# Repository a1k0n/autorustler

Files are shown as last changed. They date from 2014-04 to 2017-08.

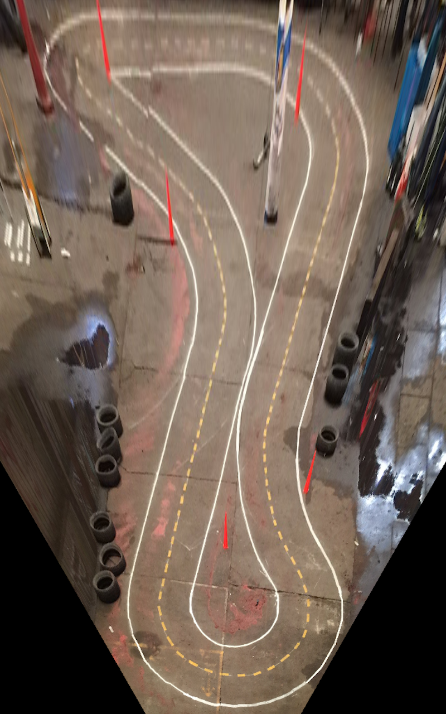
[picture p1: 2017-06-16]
diyrobocars/trackbirdseye.png

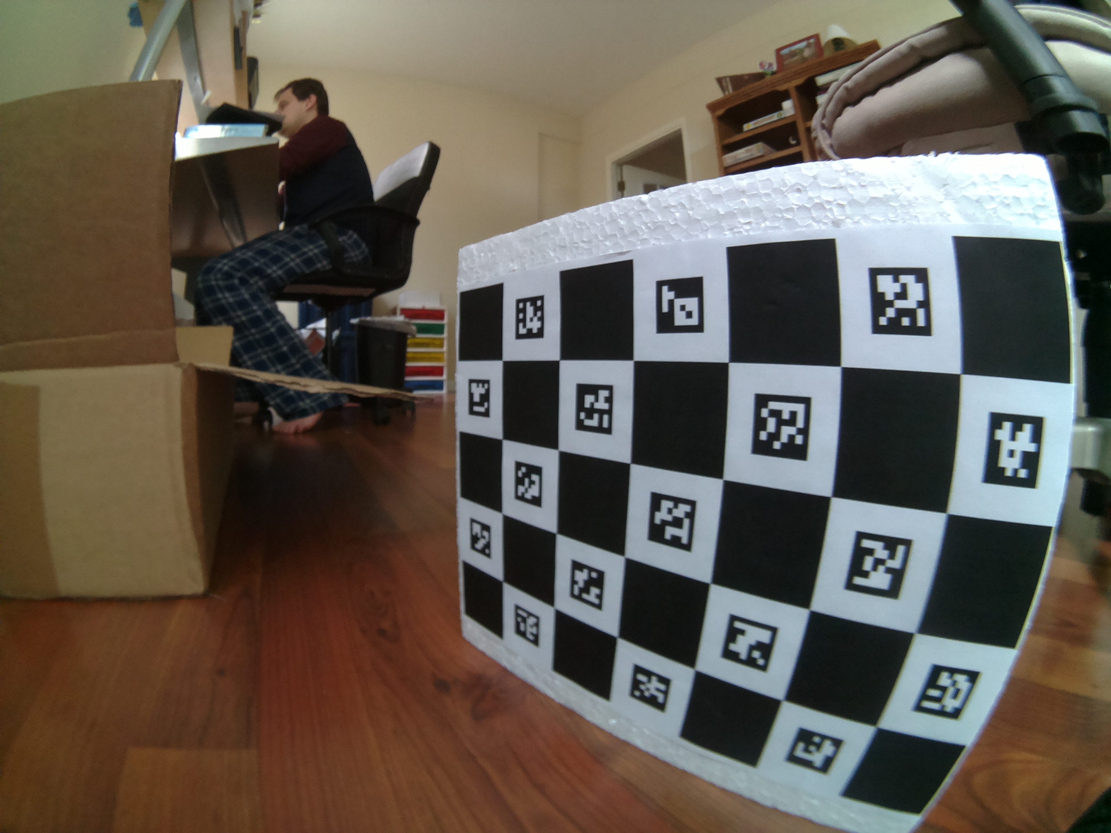
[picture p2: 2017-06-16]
camcal/cal2.jpg

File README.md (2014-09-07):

autorustler
===========

My work-in-progress self-driving RC car.

Most host code runs on a Raspberry Pi; some runs on an Atmel AVR connected to
it via SPI.

To build on a host with a raspberry pi cross-compiler (mine's called
arm-none-linux-gnueabi-gcc, you may need to edit crosscompile.cmake):

    mkdir build
    cd build
    cmake -DCMAKE_TOOLCHAIN_FILE=../crosscompile.cmake ..
    make -j4

Building on a raspberry pi is more straightforward but slow.

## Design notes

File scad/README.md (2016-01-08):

# OpenSCAD modelling for 3D-printed parts

The scad files reference some rather large .stl files (about 24MB total) for
lining up parts; type `make` to download them.

The Traxxas car model is from Claudio Caprarella:
https://grabcad.com/library/r-slash-c-car

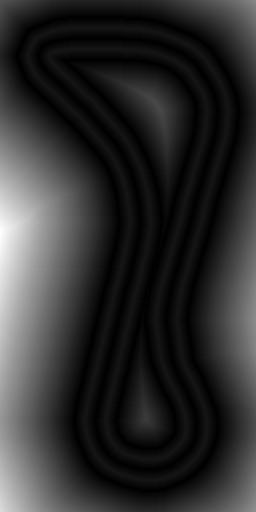
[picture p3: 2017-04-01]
diyrobocars/distmap.png

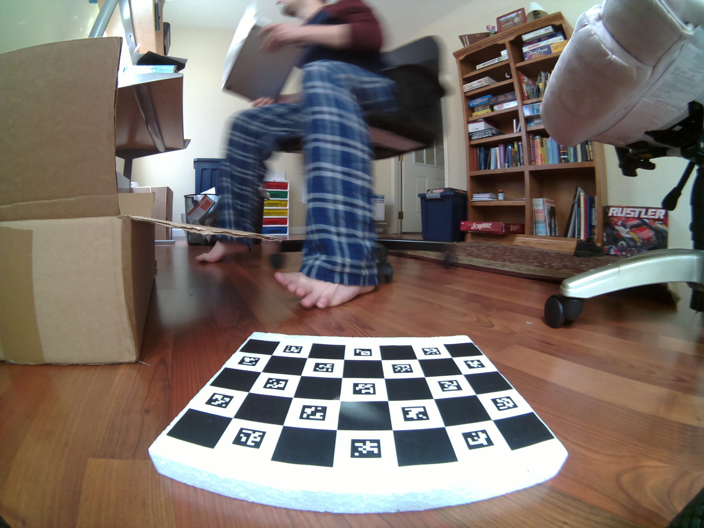
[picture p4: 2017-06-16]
camcal/cal4.jpg

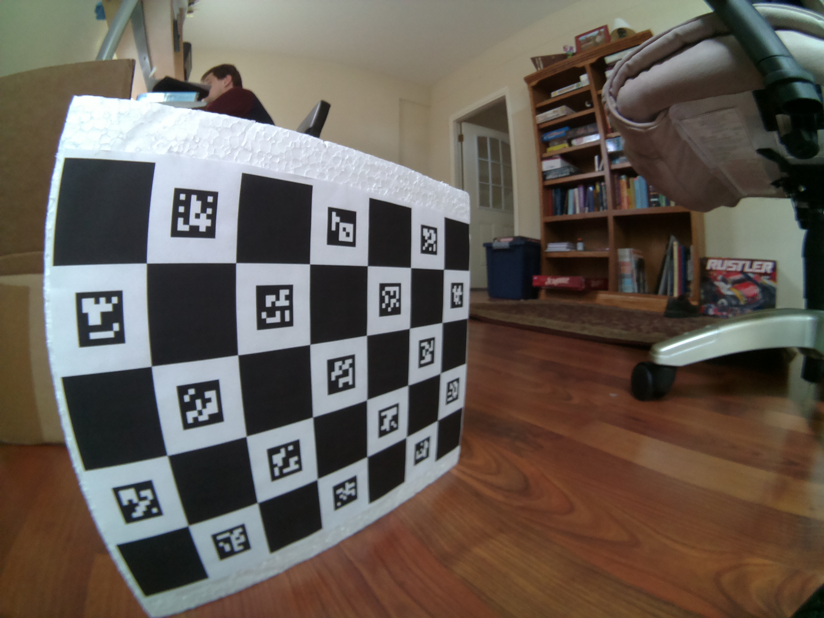
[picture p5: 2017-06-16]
camcal/cal3.jpg

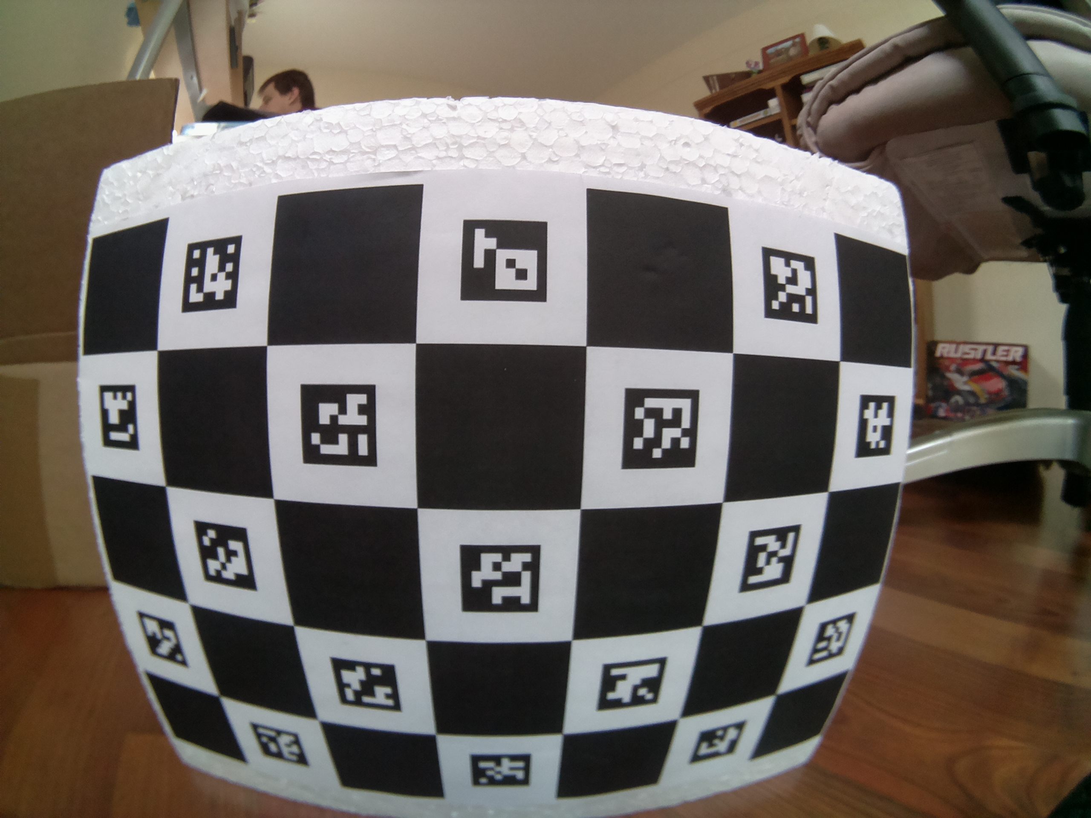
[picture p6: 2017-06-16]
camcal/cal1.jpg

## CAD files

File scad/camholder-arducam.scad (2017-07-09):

thickness = 7;
cam_border = 3;
arducam_width = 37;
arducam_height = 37;
arducam_mount = [
  [-28.5/2, 28.5/2],
  [-28.5/2, -28.5/2],
  [28.5/2, -28.5/2],
  [28.5/2, 28.5/2],
];
arducam_lens_diam = 18;
screw_diam = 2.26;  // #4-40
screw_wall_thickness = 1.2;  // must be a multiple of nozzle size 0.4
support_offset = 4;

module CameraMount() {
  difference() {
    union() {
      translate([-(cam_border + arducam_width)/2, -(cam_border + arducam_height)/2, 0])
        cube([cam_border + arducam_width, cam_border + arducam_height, thickness]);
      for (h = arducam_mount) {
        translate([h[0], h[1], thickness - 0.1]) {
          cylinder(d=screw_diam + 2*screw_wall_thickness, h=support_offset + 0.1, $fn=20);
        }
      }
    }
    for (h = arducam_mount) {
      translate([h[0], h[1], -0.1]) {
        cylinder(d=screw_diam, h=thickness + 10, $fn=10);
      }
    }
    // hole for lens
    translate([0, 0, -0.1])
      cylinder(d=arducam_lens_diam, h=thickness + 3);
  }
}

module BumperSpar(sparlen) {
  rotate([90, 0, 0]) rotate([0, 90, 0]) linear_extrude(height = 2)
    polygon(points=[
      [-1.72, 3.0],
      [sparlen, 3], [sparlen, -0.1], [0, -0.1], [-1.72, 3.0]]);
}

bb_len = 90;
module BumperBracket() {
  // 30.75 inner to inner
  // 3.5mm diameter holes (we will probably have to drill out)
  // 60 deg angle from vertical
  difference() {
    union() {
      rotate([-60, 0, 0]) {
        translate([-25, -20, 0])
          cube([50, 20, thickness]);
      }
      linear_extrude(height = thickness)
        polygon(points=[
            [-25, 0],
            [-(cam_border + arducam_width)/2, bb_len],
            [(cam_border + arducam_width)/2, bb_len],
            [25, 0], [-25, 0]]);
    }
    // translate([-12, 0, 1.0]) BumperSpar(bb_len - 5);
    // translate([10, 0, 1.0]) BumperSpar(bb_len - 5);
    rotate([-60, 0, 0]) {
      translate([-30.75/2 - 3.5/2, -6, -0.1])
        cylinder(d=4.5, h=thickness + 1, $fn=10);
      translate([-30.75/2 - 3.5/2, -6, thickness-0.1])
        cylinder(d=9, h=thickness + 1, $fn=20);
      translate([30.75/2 + 3.5/2, -6, -0.1])
        cylinder(d=4.5, h=thickness + 1, $fn=10);
      translate([30.75/2 + 3.5/2, -6, thickness-0.1])
        cylinder(d=9, h=thickness + 1, $fn=20);
    }
  }
}

BumperBracket();
translate([0, bb_len+arducam_height/2, 0]) CameraMount();

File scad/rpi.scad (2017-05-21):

// Raspberry Pi, in mm scale
// origin is centered at bottom of board
// most measurements are from my RPi own board with a dial calipers
// others from
// http://www.raspberrypi.org/raspberry-pi-rev2-template-with-mounting-holes/

RPi_length = 85;
RPi_width = 56;

RPi_mounting_holes = [
  [-RPi_length/2 + 5, -RPi_width/2 + 12.5],
  [RPi_length/2 - 25.5, RPi_width/2 - 18]
];

RPiCam_width = 25;
RPiCam_height = 24;
RPiCam_pcbdepth = 1;
RPiCam_mounting_holes = [
  [-RPiCam_width/2 + 2, RPiCam_height/2 - 2],
  [ RPiCam_width/2 - 2, RPiCam_height/2 - 2],
  [-RPiCam_width/2 + 2, -RPiCam_height/2 + 9.5],
  [ RPiCam_width/2 - 2, -RPiCam_height/2 + 9.5],
];

module HeaderPair() {
  color("black", alpha = 0.7)
    translate([0, 0, 2.5/2])
      cube([2.53, 5.08, 2.5], center=true);
  color("silver", alpha = 0.7) {
    translate([0, -1.27, 2.5])
      cube([0.6, 0.6, 11.5], center=true);
    translate([0, 1.27, 2.5])
      cube([0.6, 0.6, 11.5], center=true);
  }
}

module RPi() {
  // sd card protrusion
  sdcard_frombottom = 14;
  sdcard_width = 24;
  sdcard_bottom = RPi_width/2 - sdcard_frombottom;
  sdcard_center = sdcard_bottom - sdcard_width/2;

  pcb_h = 1.52;

  translate([0,0,pcb_h/2]) {
    // render sdcard first so it shows through the bottom
    translate([RPi_length/2 + 2, -sdcard_center, -.76-1.05])
      color([0, 0, 0, 0.5])
        cube([32, 24, 2.1], center = true);

    // circuit board itself, with mounting holes
    color([0, 0.4, 0, 0.5]) {
      difference() {
        cube([RPi_length, RPi_width, pcb_h], center = true);
        for (h = RPi_mounting_holes) {
          translate(h)
            cylinder(d = 2.9, h = 2, center = true, $fn = 20);
        }
      }
    }
  }

  // top & thru-hole components
  translate([0, 0, pcb_h - .01]) {
    // cpu & flat flex connectors
    color("black", alpha=0.7) {
      translate([-6 + 2.5, -6, 0]) cube([12, 12, 1.4]);
      translate([-RPi_length/2 + 25, RPi_width/2 - 22.5, 0]) cube([4, 22.5, 5.6]);
    }

    // P1 header is 1mm from the bottom-right
    for (i = [0 : 12]) {
      translate([RPi_length/2 - 1 - 2.54/2 - 2.54*i, -RPi_width/2 + 1 + 2.54, 0])
        HeaderPair();
    }

    // usb + ethernet + hdmi
    color("silver", alpha=0.7) {
      translate([-RPi_length/2 - 7,-RPi_width/2 + 18.5,0])
        cube([17,14.5,16]);
      translate([RPi_length/2 - 5.5, RPi_width/2 - 11.5, 0])
        cube([6, 8, 2.5]);
      translate([-RPi_length/2 - 1, RPi_width/2 - 18, 0])
        cube([21.5, 16, 14.5]);
      translate([-RPi_length/2 + 33, RPi_width/2 - 12 + .65, 0])
        cube([15, 12, 6]);
    }
  }
}

module RPiCamera() {
  // circuit board itself, with mounting holes
  color([0, 0.4, 0, 0.7]) {
    difference() {
      cube([RPiCam_width, RPiCam_height, RPiCam_pcbdepth], center = true);
      for (h = RPiCam_mounting_holes) {
        translate(h)
          cylinder(d = 2.2, h = 2, center = true, $fn = 20);
      }
    }
  }
  color([0, 0, 0, 0.7]) {
    translate([0, -2.5, 2]) {
      cube([8, 8, 4], center=true);
      translate([0,0,1.4])
        cylinder(d=7, h=2, $fn=20);
    }
  }
}

RPi();

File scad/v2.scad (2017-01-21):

include <traxxas.scad>

// All coordinates are relative to the lower-left corner of the RPi2 viewed
// from the top with the ethernet/USB on the right side.
RPi_mounting_holes = [
  [3.5, 3.5, 0],
  [3.5, 3.5 + 49, 0],
  [3.5 + 58, 3.5, 0],
  [3.5 + 58, 3.5 + 49, 0],
];

RPicam_mounting_holes = [
  [9.35, 2, 0],
  [21.85, 2, 0],
  [9.35, 23, 0],
  [21.85, 23, 0]
];

module rpi2() {
  color([0.0, 0.5, 0.2]) translate([0, -2.5, -2.0]) {
    import("rpi-bplus.stl");
  }
}

module rpicam() {
  difference() {
    color("green") cube([23.9, 25, 0.95]);
    for (h = RPicam_mounting_holes) {
      translate(h + [0, 0, -0.1]) cylinder(d = 2, h = 1.2, $fn = 20);
    }
  }
  color("black") translate([5.1, (25 - 8) / 2, 0.9]) cube([8, 8, 5.25]);
  color("beige") translate([0, 2.25, -2.8]) cube([5.6, 25 - 4.5, 2.85]);
  color("brown") translate([-20, (25 - 16.2) / 2, -1.27]) cube([20.5, 16.2, 0.1]);
}

module mountplate() {
  marginx = 5;
  marginy = 15;
  boardoffset = 3;
// need IMU, battery charger circuit
// battery itself can stick to the car body
  difference() {
    union() {
      translate([-marginx, -marginy, 0])
        cube([85 + 2*marginx, 56 + 2*marginy, 1]);
      for (h = RPi_mounting_holes) {
        translate(h + [0, 0, 0.9]) {
          cylinder(d = 6, h= 0.1 + boardoffset, $fn = 20);
        }
      }
    }
    for (h = RPi_mounting_holes) {
      translate(h + [0, 0, -0.1]) {
        cylinder(d = 2.26, h= 1.2 + boardoffset, $fn = 20);
      }
    }
  }
  #translate([0, 0, boardoffset + 1]) rpi2();
}

module cameramount() {
  rpicam();
}

module chargeboard() {
  cube([22, 37, 7]);
}

module backuplipoly() {
  cube([60, 36, 7]);
}

module car() {
  import("rustler.stl");
}

alignplate_thick = 18/2.54;
alignplate_thick2 = 6/2.54;
alignplate_radius = 24/2.54;
Servoplate_width = 124;
module alignplate_shape() {
  r = alignplate_radius;
  linear_extrude(alignplate_thick) {
    minkowski() {
      circle(r=r);
      polygon(points = [
          [-Servoplate_width/2 + 19, 253/2],
          [-Servoplate_width/2 + 50 - r, 114/2 - r],
          [-Servoplate_width/2 + 165 - r, 114/2 - r],
          [Servoplate_width/2 - 20, 134/2],
          [Servoplate_width/2 - 20, -134/2],
          [-Servoplate_width/2 + 165 - r, -114/2 + r],
          [-Servoplate_width/2 + 50 - r, -114/2 + r],
          [-Servoplate_width/2 + 19, -253/2]]);
    }
  }
}

module alignplate_base() {
  overbore = 2;
  r = alignplate_radius;
  difference() {
    alignplate_shape();
    difference() {
      // thin the plate out where not necessary to be thick, but leave a
      // rigidity spar in the middle
      union() {
        translate([-250 - r, -110, alignplate_thick2])
          cube([450 + r, 220, alignplate_thick - alignplate_thick2 + 0.1]);
        translate([200, -45, alignplate_thick2])
          cube([30, 90, alignplate_thick - alignplate_thick2 + 0.1]);
      }
      // spar for rigidity
      translate([-Servoplate_width/2 + 30, -4, alignplate_thick2 - 0.1])
        cube([Servoplate_width - 35, 8, 8]);
    }

    // battery holder clearance
    translate([-Servoplate_width/2 - r - 0.1, -189/2, -0.1])
      cube([15.1 + r, 189, 17.2]);
    translate([-Servoplate_width/2 - r - 0.1, -61/2, -0.1])
      cube([30.1 + r, 61, 17.2]);

    // 4mm (.16) holes .20 from the right edge, 1.34" apart
    translate([Servoplate_width/2 - 20, 134/2, alignplate_thick])
      m4flushscrew(h=20);
    translate([Servoplate_width/2 - 20, -134/2, alignplate_thick])
      m4flushscrew(h=20);
    // 3mm (.12) holes .19 from the left edge, 2.53" apart
    translate([-Servoplate_width/2 + 19, 253/2, alignplate_thick])
      m3flushscrew(h=20);
    translate([-Servoplate_width/2 + 19, -253/2, alignplate_thick])
      m3flushscrew(h=20);

    // weird doohicky on the front
    translate([Servoplate_width/2 - 38 - 17 - 8, -48/2 - 8, -0.1])
      cube([17+ 16, 48+ 16, 27.1]);
    translate([Servoplate_width/2 - 28 - 33 - 8, -12/2 - 8, -0.1])
      cube([28+ 16, 12+ 16, 47.1]);
  }
}

*translate([-20 - 85/2, -56/2, 40]) mountplate();
*cameramount();
*rotate([90, 0, 0]) scale(10.0) color("gray") car();
*translate([10, -65, 10]) backuplipoly();

*translate([-121, 0, 100]) rotate([0, 0, 180]) servoholder();
#servoholder();
alignplate_base();

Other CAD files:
scad/baseplate.scad
scad/camholder.scad
scad/fasteners.scad
scad/traxxas.scad

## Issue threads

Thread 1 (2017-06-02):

I made a mistake while compiling the UI package

zhyb86, 2017-06-02:
/home/pi/autorustler/ui/imu.cc: In function ‘void* IMUThread(void*)’:
/home/pi/autorustler/ui/imu.cc:16:7: error: no matching function for call to ‘IMU::IMU()’
IMU imu;
    ^
/home/pi/autorustler/ui/imu.cc:16:7: note: candidates are:In file included from /home/pi/autorustler/ui/imu.cc:8:0:/home/pi/autorustler/imu/imu.h:25:12: note: IMU::IMU(const I2C&)
explicit IMU(const I2C &i2c) : i2c_(i2c), YTY_(10, 10) {}    
         ^
/home/pi/autorustler/imu/imu.h:25:12: note:   candidate expects 1 argument, 0 provided
/home/pi/autorustler/imu/imu.h:23:7: note: IMU::IMU(const IMU&)
class IMU {
      ^
/home/pi/autorustler/imu/imu.h:23:7: note:   candidate expects 1 argument, 0 provided
/home/pi/autorustler/ui/imu.cc:17:22: error: no matching function for call to ‘IMU::Init(int&)’
if (!imu.Init(i2cfd)) {              
                   ^
/home/pi/autorustler/ui/imu.cc:17:22: note: candidate is:In file included from /home/pi/autorustler/ui/imu.cc:8:0:/home/pi/autorustler/imu/imu.h:27:8: note: bool IMU::Init()
bool Init();
     ^
/home/pi/autorustler/imu/imu.h:27:8: note:   candidate expects 0 arguments, 1 provided
/home/pi/autorustler/ui/imu.cc:23:11: error: ‘class RadioControl’ has no member named ‘Init’
if (!rc.Init()) {   
        ^
/home/pi/autorustler/ui/imu.cc:37:14: error: ‘class IMU’ has no member named ‘ReadRaw’
if (!imu.ReadRaw(&s)) {      
         ^
/home/pi/autorustler/ui/imu.cc:41:9: error: ‘class IMU’ has no member named ‘Calibrate’
imu.Calibrate(s, &uistate.imu_state); 
    ^
ui/CMakeFiles/ui.dir/build.make:134: recipe for target 'ui/CMakeFiles/ui.dir/imu.cc.o' faile
dmake[2]: *** [ui/CMakeFiles/ui.dir/imu.cc.o] Error 1
CMakeFiles/Makefile2:5449: recipe for target 'ui/CMakeFiles/ui.dir/all' failed
make[1]: *** [ui/CMakeFiles/ui.dir/all] Error 2
Makefile:149: recipe for target 'all'
failedmake: *** [all] Error 2

a1k0n, 2017-06-02:
Sorry, the UI package is dead code from several iterations ago. I might as well just remove it.

a1k0n, 2017-06-02:
I haven't done a good job of documenting anything in here, really... "drive" is the main program now; it's controlled with a bluetooth controller and has no display.

Closed 2017-06-02.

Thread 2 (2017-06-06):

I'm running the "cal.py" tooltip error

zhyb86, 2017-06-06:
Traceback (most recent call last):
  File "cal.py", line 3, in <module>
    import cv2.aruco
ImportError: No module named aruco

a1k0n, 2017-06-06:
I think aruco is only available in opencv 3.x, within the opencv_contrib module. I ended up compiling it myself. The module is still named `cv2` despite being opencv 3.

zhyb86, 2017-06-07:
Thanks a lot for your reply. Can you share the mirrored images of raspberry pie? Cause I'm troubled in building the aruco module. Any web disks for sharing is ok. Thanks again.

a1k0n, 2017-06-07:
Oh, my project actually doesn't use opencv at all on the Raspberry Pi. I use Aruco to calibrate my camera on my macbook and precompute a camera pixel -> ground plane position lookup table which is used on the car (`drive/udplane.h`)

zhyb86, 2017-06-08:
Lane identification, display interface running that program? Or procedures for vehicle status

a1k0n, 2017-06-09:
You mean the videos in my Twitter feed? Those are produced in ad-hoc ipython notebooks by recording data from the car and copying to my laptop. there's no real-time display. The most recent ones are produced by `diyrobocars/ekf_numeric.ipynb`.

zhyb86, 2017-06-12:
Thanks a lot for your reply.

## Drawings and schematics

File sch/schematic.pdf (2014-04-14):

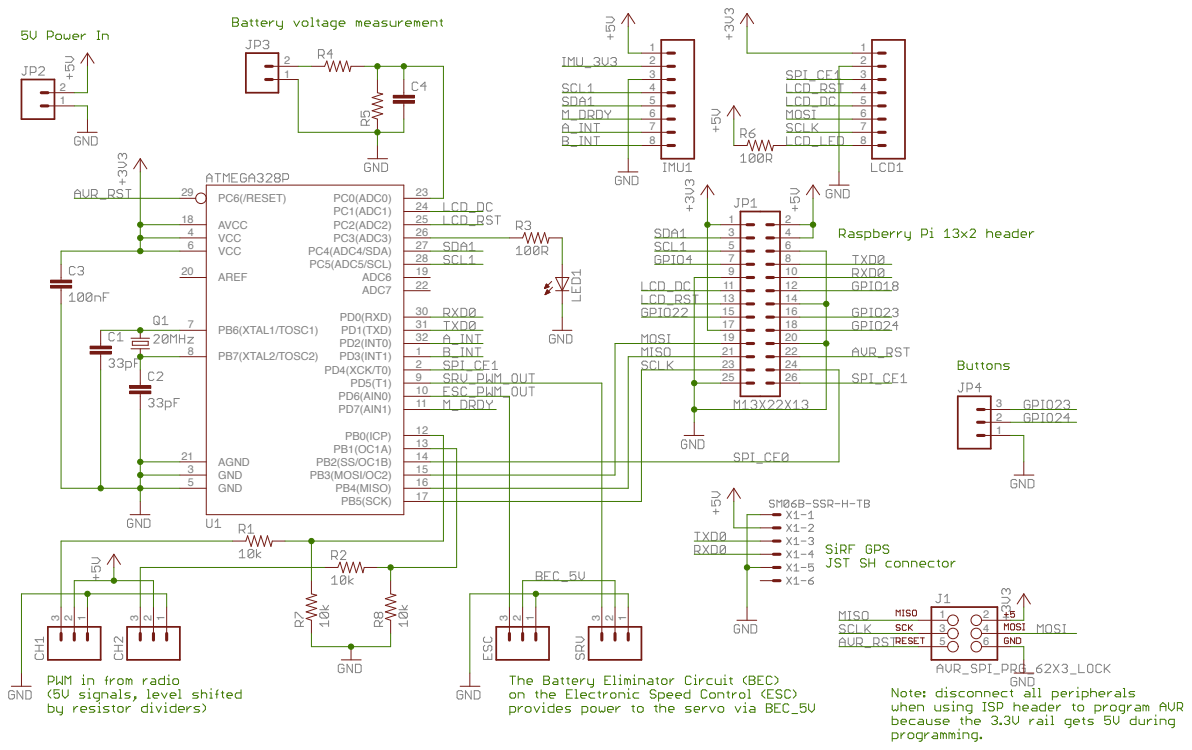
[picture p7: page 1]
PB5(SCK); PB7(XTAL2/TOSC2); PB6(XTAL1/TOSC1); GND; VCC; AGND 21; AREF 20; AVCC 18; PB4(MISO); 16 PB3(MOSI/OC2); 13 PB0(ICP); PD7(AIN1); 11 PD6(AIN0); 9 PD4(XCK/T0); 2 PD3(INT1); 1 PD2(INT0); 32 PD1(TXD); 31 PD0(RXD); ADC7; 22 ADC6; 19 PC5(ADC5/SCL); 28 PC4(ADC4/SDA); 27 PC3(ADC3); 26 PC2(ADC2); 25 PC1(ADC1); 24 PC0(ADC0); 23 PC6(/RESET) 29

11 | 12
13 | | 14
15 | | 16
17 | 18

3 4
5 6

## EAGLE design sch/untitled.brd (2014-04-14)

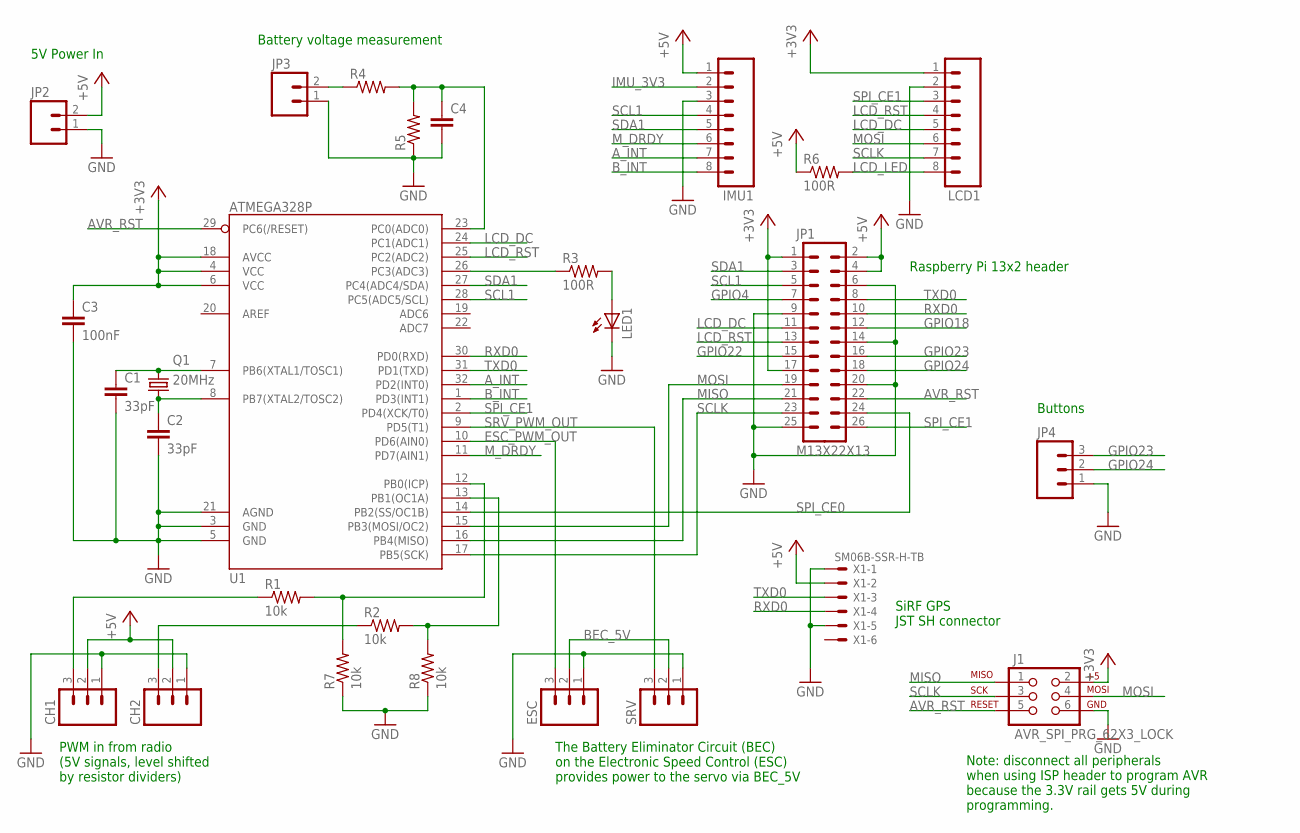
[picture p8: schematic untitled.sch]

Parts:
C1, C2: 33pF; 0805
C3: 100nF; 0805
C4: CAP0805; 0805
CH1, CH2: M03LOCK; 1X03_LOCK
ESC: M03LOCK; 1X03_LOCK
IMU1: M08LOCK; 1X08_LOCK
J1: AVR_SPI_PRG_62X3_LOCK; 2X3_LOCK
JP1: M13X22X13; 2X13
JP2, JP3: M02POLAR_LOCK; MOLEX-1X2_LOCK
JP4: M03POLAR_LOCK; MOLEX-1X3_LOCK
LCD1: M08LOCK; 1X08_LOCK
LED1: LED3MM
Q1: 20MHz; SM49
R1, R2, R7, R8: 10k; 0805
R3, R6: 100R; 0805
R4, R5: RESISTOR0805-RES; 0805
SRV: M03LOCK; 1X03_LOCK
U1: ATMEGA328P; TQFP32-08
X1: SM06B-SSR-H-TB

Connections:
+3V3: C3.1, J1.2, JP1.1, JP1.17, LCD1.1, U1.4 (VCC), U1.6 (VCC), U1.18 (AVCC)
+5V: CH1.2, CH2.2, IMU1.1, JP1.2, JP1.4, JP2.2, R6.1, X1.2
AVR_RST: J1.5, JP1.22, U1.29 (PC6(/RESET))
A_INT: IMU1.7, U1.32 (PD2(INT0))
BEC_5V: ESC.2, SRV.2
B_INT: IMU1.8, U1.1 (PD3(INT1))
ESC_PWM_OUT: ESC.3, U1.10 (PD6(AIN0))
GND: C1.2, C2.2, C3.2, C4.2, CH1.1, CH2.1, ESC.1, IMU1.3, J1.6, JP1.6, JP1.9, JP1.14, JP1.20, JP1.25, JP2.1, JP3.1, JP4.1, LCD1.2, LED1.K (C), R5.1, R7.1, R8.1, SRV.1, U1.3 (GND), U1.5 (GND), U1.21 (AGND), X1.1, X1.5
GPIO4: JP1.7
GPIO18: JP1.12
GPIO22: JP1.15
GPIO23: JP1.16, JP4.3
GPIO24: JP1.18, JP4.2
IMU_3V3: IMU1.2
LCD_DC: JP1.11, LCD1.5, U1.24 (PC1(ADC1))
LCD_LED: LCD1.8, R6.2
LCD_RST: JP1.13, LCD1.4, U1.25 (PC2(ADC2))
MISO: J1.1, JP1.21, U1.16 (PB4(MISO))
MOSI: J1.4, JP1.19, LCD1.6, U1.15 (PB3(MOSI/OC2))
M_DRDY: IMU1.6, U1.11 (PD7(AIN1))
unnamed: C1.1, Q1.1, U1.7 (PB6(XTAL1/TOSC1))
unnamed: C2.1, Q1.2, U1.8 (PB7(XTAL2/TOSC2))
unnamed: R3.1, U1.26 (PC3(ADC3))
unnamed: R1.2, R7.2, U1.12 (PB0(ICP))
unnamed: R2.2, R8.2, U1.13 (PB1(OC1A))
unnamed: CH1.3, R1.1
unnamed: CH2.3, R2.1
unnamed: LED1.A, R3.2
unnamed: JP3.2, R4.1
unnamed: C4.1, R4.2, R5.2, U1.23 (PC0(ADC0))
RXD0: JP1.10, U1.30 (PD0(RXD)), X1.4
SCL1: IMU1.4, JP1.5, U1.28 (PC5(ADC5/SCL))
SCLK: J1.3, JP1.23, LCD1.7, U1.17 (PB5(SCK))
SDA1: IMU1.5, JP1.3, U1.27 (PC4(ADC4/SDA))
SPI_CE0: JP1.24, U1.14 (PB2(SS/OC1B))
SPI_CE1: JP1.26, LCD1.3, U1.2 (PD4(XCK/T0))
SRV_PWM_OUT: SRV.3, U1.9 (PD5(T1))
TXD0: JP1.8, U1.31 (PD1(TXD)), X1.3

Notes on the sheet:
The Battery Eliminator Circuit (BEC) on the Electronic Speed Control (ESC) provides power to the servo via BEC_5V
PWM in from radio (5V signals, level shifted by resistor dividers)
5V Power In
Battery voltage measurement
SiRF GPS JST SH connector
Note: disconnect all peripherals when using ISP header to program AVR because the 3.3V rail gets 5V during programming.
Raspberry Pi 13x2 header
Buttons

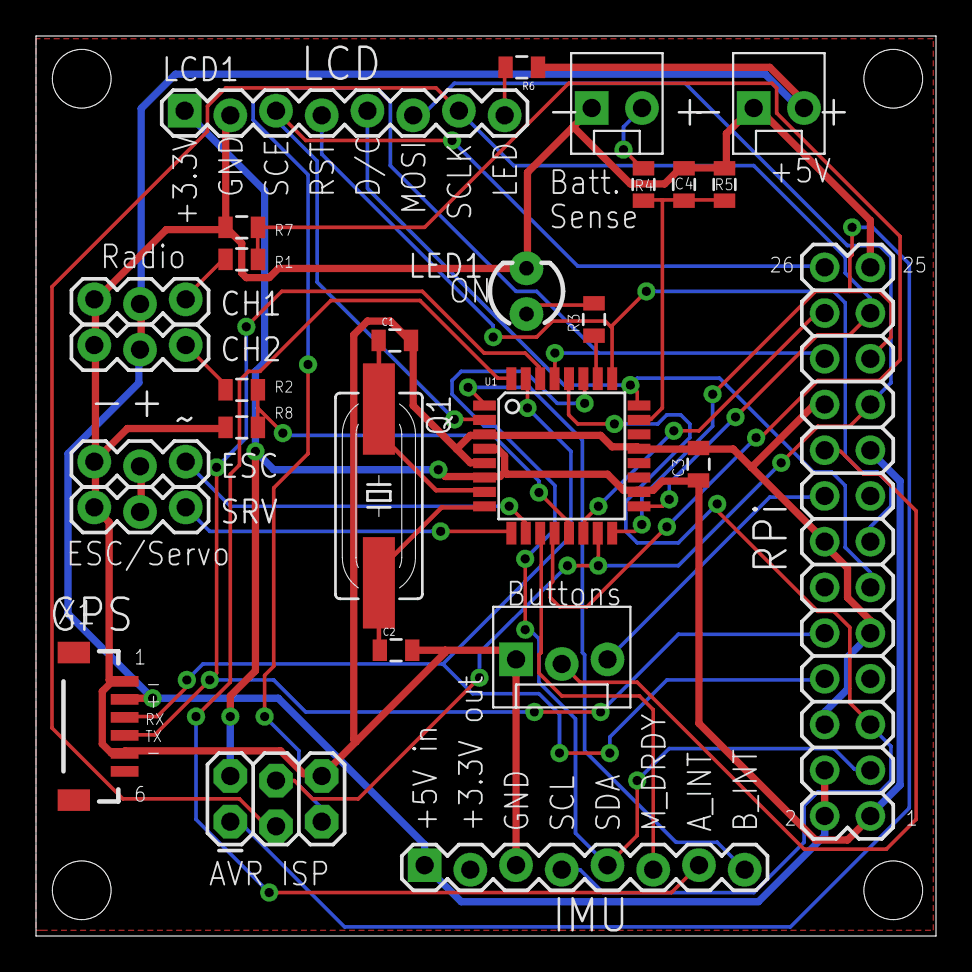
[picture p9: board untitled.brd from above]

Board: 2 copper layers, 50.0 x 50.0 mm, 27 parts (0 on the bottom side), 34 nets.

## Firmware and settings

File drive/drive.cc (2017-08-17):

#include <fcntl.h>
#include <fenv.h>
#include <pthread.h>
#include <semaphore.h>
#include <signal.h>
#include <stdio.h>
#include <string.h>
#include <sys/time.h>
#include <unistd.h>

#include <deque>

#include "cam/cam.h"
// #include "car/pca9685.h"
#include "car/teensy.h"
#include "drive/controller.h"
#include "gpio/i2c.h"
#include "imu/imu.h"
#include "input/js.h"

volatile bool done = false;
int8_t throttle_ = 0, steering_ = 0;

const int PWMCHAN_STEERING = 14;
const int PWMCHAN_ESC = 15;

void handle_sigint(int signo) { done = true; }

I2C i2c;
// PCA9685 pca(i2c);
Teensy teensy(i2c);
IMU imu(i2c);
Eigen::Vector3f accel_(0, 0, 0), gyro_(0, 0, 0);
uint8_t servo_pos_ = 110;
uint16_t wheel_pos_[4] = {0, 0, 0, 0};
uint16_t wheel_dt_[4] = {0, 0, 0, 0};

// asynchronous flush to sdcard
struct FlushEntry {
  int fd_;
  uint8_t *buf_;
  size_t len_;

  FlushEntry() { buf_ = NULL; }
  FlushEntry(int fd, uint8_t *buf, size_t len):
    fd_(fd), buf_(buf), len_(len) {}

  void flush() {
    if (len_ == -1) {
      fprintf(stderr, "FlushThread: closing fd %d\n", fd_);
      close(fd_);
    }
    if (buf_ != NULL) {
      if (write(fd_, buf_, len_) != len_) {
        perror("FlushThread write");
      }
      delete[] buf_;
      buf_ = NULL;
    }
  }
};

class FlushThread {
 public:
  FlushThread() {
    pthread_mutex_init(&mutex_, NULL);
    sem_init(&sem_, 0, 0);
  }

  ~FlushThread() {
    // terminate the thread?
  }

  bool Init() {
    if (pthread_create(&thread_, NULL, thread_entry, this) != 0) {
      perror("FlushThread: pthread_create");
      return false;
    }
    return true;
  }

  void AddEntry(int fd, uint8_t *buf, size_t len) {
    static int count = 0;
    pthread_mutex_lock(&mutex_);
    flush_queue_.push_back(FlushEntry(fd, buf, len));
    size_t siz = flush_queue_.size();
    pthread_mutex_unlock(&mutex_);
    sem_post(&sem_);
    count++;
    if (count >= 15) {
      if (siz > 2) {
        fprintf(stderr, "[FlushThread %d]\r", siz);
        fflush(stderr);
      }
      count = 0;
    }
#if 0
    int semval;
    sem_getvalue(&sem_, &semval);
    fprintf(stderr, "Flusher: qsize %d sem %d\n", flush_queue_.size(), semval);
#endif
  }

 private:
  static void* thread_entry(void* arg) {
    FlushThread *self = reinterpret_cast<FlushThread*>(arg);

    fprintf(stderr, "FlushThread: started\n");

    for (;;) {
      sem_wait(&self->sem_);
      pthread_mutex_lock(&self->mutex_);
      if (!self->flush_queue_.empty()) {
        FlushEntry e = self->flush_queue_.front();
        self->flush_queue_.pop_front();
        pthread_mutex_unlock(&self->mutex_);
        e.flush();
      } else {
        pthread_mutex_unlock(&self->mutex_);
      }
    }
  }

  std::deque<FlushEntry> flush_queue_;
  pthread_mutex_t mutex_;
  pthread_t thread_;
  sem_t sem_;
};

FlushThread flush_thread_;

class Driver: public CameraReceiver {
 public:
  Driver() {
    output_fd_ = -1;
    frame_ = 0;
    frameskip_ = 0;
    autosteer_ = false;
    gettimeofday(&last_t_, NULL);
  }

  bool StartRecording(const char *fname, int frameskip) {
    frameskip_ = frameskip;
    if (!strcmp(fname, "-")) {
      output_fd_ = fileno(stdout);
    } else {
      output_fd_ = open(fname, O_CREAT|O_TRUNC|O_WRONLY, 0666);
    }
    if (output_fd_ == -1) {
      perror(fname);
      return false;
    }
    return true;
  }

  bool IsRecording() {
    return output_fd_ != -1;
  }

  void StopRecording() {
    if (output_fd_ == -1) {
      return;
    }
    flush_thread_.AddEntry(output_fd_, NULL, -1);
    output_fd_ = -1;
  }

  ~Driver() {
    StopRecording();
  }

  void OnFrame(uint8_t *buf, size_t length) {
    struct timeval t;
    gettimeofday(&t, NULL);
    frame_++;
    if (IsRecording() && frame_ > frameskip_) {
      frame_ = 0;
      // for now: save U channel below ytop only!
      static const int ytop = 100;
      uint32_t flushlen = 55 + (240-ytop) * 320;
      // copy our frame, push it onto a stack to be flushed
      // asynchronously to sdcard
      uint8_t *flushbuf = new uint8_t[flushlen];
      memcpy(flushbuf, &flushlen, 4);  // write header length
      memcpy(flushbuf+4, &t.tv_sec, 4);
      memcpy(flushbuf+8, &t.tv_usec, 4);
      memcpy(flushbuf+12, &throttle_, 1);
      memcpy(flushbuf+13, &steering_, 1);
      memcpy(flushbuf+14, &accel_[0], 4);
      memcpy(flushbuf+14+4, &accel_[1], 4);
      memcpy(flushbuf+14+8, &accel_[2], 4);
      memcpy(flushbuf+26, &gyro_[0], 4);
      memcpy(flushbuf+26+4, &gyro_[1], 4);
      memcpy(flushbuf+26+8, &gyro_[2], 4);
      memcpy(flushbuf+38, &servo_pos_, 1);
      memcpy(flushbuf+39, wheel_pos_, 2*4);
      memcpy(flushbuf+47, wheel_dt_, 2*4);
      memcpy(flushbuf+55, buf + 640*480 + ytop*320, (240-ytop)*320);

      struct timeval t1;
      gettimeofday(&t1, NULL);
      float dt = t1.tv_sec - t.tv_sec + (t1.tv_usec - t.tv_usec) * 1e-6;
      if (dt > 0.1) {
        fprintf(stderr, "CameraThread::OnFrame: WARNING: "
            "alloc/copy took %fs\n", dt);
      }

      flush_thread_.AddEntry(output_fd_, flushbuf, flushlen);
      struct timeval t2;
      gettimeofday(&t2, NULL);
      dt = t2.tv_sec - t1.tv_sec + (t2.tv_usec - t1.tv_usec) * 1e-6;
      if (dt > 0.1) {
        fprintf(stderr, "CameraThread::OnFrame: WARNING: "
            "flush_thread.AddEntry took %fs\n", dt);
      }
    }

    {
      static struct timeval t0 = {0,0};
      float dt = t.tv_sec - t0.tv_sec + (t.tv_usec - t0.tv_usec) * 1e-6;
      if (dt > 0.1) {
        fprintf(stderr, "CameraThread::OnFrame: WARNING: "
            "%fs gap between frames?!\n", dt);
      }
      t0 = t;
    }


    float u_a = throttle_ / 127.0;
    float u_s = steering_ / 127.0;
    float dt = t.tv_sec - last_t_.tv_sec + (t.tv_usec - last_t_.tv_usec) * 1e-6;
    controller_.UpdateState(buf, length,
            u_a, u_s,
            accel_, gyro_,
            servo_pos_, wheel_pos_,
            dt);
    last_t_ = t;

    if (autosteer_ && controller_.GetControl(&u_a, &u_s, dt)) {
      steering_ = 127 * u_s;
      throttle_ = 127 * u_a;
      teensy.SetControls(frame_ & 4 ? 1 : 0, throttle_, steering_);
      // pca.SetPWM(PWMCHAN_STEERING, steering_);
      // pca.SetPWM(PWMCHAN_ESC, throttle_);
    }
  }

  bool autosteer_;
  DriveController controller_;
  int frame_;

 private:
  int output_fd_;
  int frameskip_;
  struct timeval last_t_;
};

static inline float clip(float x, float min, float max) {
  if (x < min) return min;
  if (x > max) return max;
  return x;
}

int main(int argc, char *argv[]) {
  signal(SIGINT, handle_sigint);

  feenableexcept(FE_INVALID | FE_DIVBYZERO | FE_OVERFLOW | FE_UNDERFLOW);

  if (argc < 2) {
    fprintf(stderr, "%s [[output.yuv] [fps]\n", argv[0]);
    return 1;
  }

  int fps = 30;
  int frameskip = 0;

  if (argc > 2) {
    fps = atoi(argv[2]);
    if (fps == 0) {
      fprintf(stderr, "invalid fps %d\n", fps);
      return 1;
    }
  }

  if (!flush_thread_.Init()) {
    return 1;
  }

  if (!Camera::Init(640, 480, fps))
    return 1;

  JoystickInput js;

  if (!i2c.Open()) {
    return 1;
  }

  bool has_joystick = false;
  if (js.Open()) {
    has_joystick = true;
  } else {
    fprintf(stderr, "joystick not detected!\n");
  }

  teensy.Init();
  teensy.SetControls(0, 0, 0);
  teensy.GetFeedback(&servo_pos_, wheel_pos_, wheel_dt_);
  fprintf(stderr, "initial teensy state feedback: \n"
          "  servo %d encoders %d %d %d %d\r",
          servo_pos_, wheel_pos_[0], wheel_pos_[1],
          wheel_pos_[2], wheel_pos_[3]);

  // pca.Init(100);  // 100Hz output
  // pca.SetPWM(PWMCHAN_STEERING, 614);
  // pca.SetPWM(PWMCHAN_ESC, 614);

  imu.Init();

  struct timeval tv;
  gettimeofday(&tv, NULL);
  fprintf(stderr, "%d.%06d camera on @%d fps\n", tv.tv_sec, tv.tv_usec, fps);

  Driver driver;
  if (!Camera::StartRecord(&driver)) {
    return 1;
  }

  gettimeofday(&tv, NULL);
  fprintf(stderr, "%d.%06d started camera\n", tv.tv_sec, tv.tv_usec);

  int recording_num = 0;

  while (!done) {
    int t = 0, s = 0;
    uint16_t b = 0;
    if (has_joystick && js.ReadInput(&t, &s, &b)) {
      gettimeofday(&tv, NULL);
      if ((b & 0x40) && !driver.IsRecording()) {  // start button: start recording
        char fnamebuf[256];
        snprintf(fnamebuf, sizeof(fnamebuf), "%s-%d.yuv", argv[1], recording_num++);
        if (driver.StartRecording(fnamebuf, frameskip)) {
          fprintf(stderr, "%d.%06d started recording %s %d/%d fps\n", tv.tv_sec, tv.tv_usec, fnamebuf, fps, frameskip+1);
        }
      }
      if (b & 0x20 && driver.IsRecording()) {
        driver.StopRecording();
        fprintf(stderr, "%d.%06d stopped recording\n", tv.tv_sec, tv.tv_usec);
      }

      if (b & 0x10) {  // not sure which button this is
        if (!driver.autosteer_) {
          fprintf(stderr, "%d.%06d autosteer ON\n", tv.tv_sec, tv.tv_usec);
          driver.autosteer_ = true;
        }
      } else {
        if (driver.autosteer_) {
          driver.autosteer_ = false;
          fprintf(stderr, "%d.%06d autosteer OFF\n", tv.tv_sec, tv.tv_usec);
        }
      }

      if (b & 0x01) {
        driver.controller_.ResetState();
        fprintf(stderr, "reset kalman filter\n");
      }

      if (!driver.autosteer_) {
        steering_ = clip(-127*s / 32767.0, -127, 127);
        throttle_ = clip(127*t / 32767.0, -127, 127);
        // pca.SetPWM(PWMCHAN_STEERING, steering_);
        // pca.SetPWM(PWMCHAN_ESC, throttle_);
        teensy.SetControls(driver.frame_ & 16 ? 1 : 0, throttle_, steering_);
      }
    }
    // FIXME: predict step here?
    {
      float temp;
      imu.ReadIMU(&accel_, &gyro_, &temp);
      // FIXME: imu EKF update step?
      teensy.GetFeedback(&servo_pos_, wheel_pos_, wheel_dt_);
    }
    usleep(1000);
  }

  Camera::StopRecord();
}

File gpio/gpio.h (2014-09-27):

#ifndef LCD_GPIO_H_
#define LCD_GPIO_H_

// I/O access
extern volatile unsigned *gpio;

// GPIO setup macros. Always use INP_GPIO(x) before using OUT_GPIO(x) or
// SET_GPIO_ALT(x,y)
#define INP_GPIO(g) *(gpio+((g)/10)) &= ~(7 << (((g)%10)*3))
#define OUT_GPIO(g) *(gpio+((g)/10)) |=  (1 << (((g)%10)*3))
#define SET_GPIO_ALT(g, a) *(gpio+(((g)/10))) |= \
            (((a) <= 3?(a)+4:(a) == 4?3:2) << (((g)%10)*3))

#define GPIO_SET *(gpio+7)   // sets bits which are 1
#define GPIO_CLR *(gpio+10)  // clears bits which are 1

#define GPIO_IN0   *(gpio+13)  // Reads GPIO input bits 0-31

#define GPIO_PULL   *(gpio+37)    // Pull up/pull down
#define GPIO_PULLCLK0 *(gpio+38)  // Pull up/pull down clock

#define GET_GPIO(g) (*(gpio+13) & (1 << g))  // 0 if LOW, (1<<g) if HIGH

bool gpio_init();  // N.B. must be root

#endif  // LCD_GPIO_H_

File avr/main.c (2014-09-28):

#include <avr/interrupt.h>
#include <avr/io.h>
#include <avr/pgmspace.h>
#include <avr/wdt.h>
#include <util/delay.h>

static uint16_t battery_voltage = 0;

volatile static uint8_t ch1_counts = 0, ch2_counts = 0;
volatile static uint8_t pwm_mirror = 1;
ISR(PCINT0_vect) {
  static uint8_t ch1_start = 0, ch2_start = 0;
  static uint8_t ch1_state = 0, ch2_state = 0;
  uint8_t tm = TCNT0;
  uint8_t state = PINB;
  if ((state&1) != ch1_state) {
    ch1_state = state&1;
    if (ch1_state) {
      ch1_start = tm;
    } else {
      ch1_counts = (tm - ch1_start);
    }
  }
  if ((state&2) != ch2_state) {
    ch2_state = state&2;
    if (ch2_state) {
      ch2_start = tm;
    } else {
      ch2_counts = (tm - ch1_start);
    }
  }
}

// dumb int-on-pin-change pwm capture
static void pwmcapture_init() {
  PORTB = 0x03;  // add pull-ups to inputs
  PCMSK0 = 0x03;
  PCICR = 0x01;
}

ISR(SPI_STC_vect) {
  uint8_t spi_in = SPDR;
  static uint8_t spi_state = 0, spi_hibyte = 0;
  static uint8_t spi_readlen = 0;
  switch (spi_state) {
    default:  // command mode, state 0 (or invalid states)
      if (spi_in == 0x01) {  // command 0x01: read timer
        SPDR = TCNT1L;
        spi_hibyte = TCNT1H;
        spi_state = 1;
      } else if (spi_in == 0x02) {  // command 0x02: read PWM input state
        SPDR = ch1_counts;
        spi_hibyte = ch2_counts;
        spi_state = 1;
      } else if (spi_in == 0x03) {  // command 0x03: set pwm mirroring
        SPDR = 1 + (pwm_mirror << 1);
        spi_state = 5;
      } else if (spi_in == 0x04) {  // command 0x04: set pwm output
        SPDR = 1;
        spi_state = 6;
      } else if (spi_in == 0x05) {  // command 0x05: get battery voltage
        SPDR = battery_voltage & 0xff;
        spi_hibyte = battery_voltage >> 8;
        spi_state = 1;
      } else {  // unknown command, or padding (command 0)
        SPDR = 0;
      }
      break;
    case 1: // send one high byte, then return to state 0
      SPDR = spi_hibyte;
      spi_state = 0;
      break;
    case 5: // set PWM mirror
      pwm_mirror = spi_in;
      SPDR = 0;
      spi_state = 0;
      break;
    case 6: // set PWM output ch1
      SPDR = OCR0A;
      OCR0A = spi_in;
      spi_state++;
      break;
    case 7: // set PWM output ch2
      SPDR = OCR0B;
      OCR0B = spi_in;
      spi_state = 0;
      break;
  }
}

static void spi_init() {
  // PB3 (MOSI), PB5 (SCK), PB2 (/SS) input
  // PB4 (MISO) output
  DDRB |= 0x10;
  // enable SPI
  SPCR = (1<<SPE) | (1<<SPIE);
}

static void pwmgen_init() {
  // Generate PWM on PD6/PD5 (OC0A/OC0B respectively)
  // ugh, this is only 8-bit PWM, though, and at ~300Hz.  i hope that
  // works.
  // set TMR0 prescaler to /256
  DDRD |= (1<<5) | (1<<6);

  // period in ms = 65536/F_CPU
  // duration of N counts (milliseconds) = T = 256000*n/F_CPU
  // n = T*F_CPU/256000
  OCR0A = (1.5*F_CPU/256000);
  OCR0B = (1.5*F_CPU/256000);
  // (at 20MHz this gives a dynamic range of 78-156, 117 being center)
  // so ~6.3 bit pwm...

  TCCR0A = 0xA3; // enable OC0A, OC0B, fast PWM mode
  TCCR0B = 0x04; // prescaler /256, 305.1Hz (3.2768ms cycle)
}

int main() {
  // enable WDT
  wdt_enable(WDTO_15MS);

  // Set up TMR1 to count up on each clock cycle (20MHz)
  TCCR1B = 0x01;

  // set up ADC on channel 0
  PORTC = 0;
  DDRC = 1<<3;
  DIDR0 = 0x01;
  ADMUX = 0xc0;  // internal 1.1V ref, select ADC0
  ADCSRA = 0x87;  // enable ADC

  spi_init();
  pwmcapture_init();
  pwmgen_init();

  sei();

  uint32_t itercount = 0;
  for (;;) {
    itercount++;
    wdt_reset();
    if (!(itercount&0x7ffff)) {
      PORTC ^= 1<<3;
      ADCSRA |= _BV(ADSC);
      while(!bit_is_set(ADCSRA,ADIF));
      ADCSRA |= _BV(ADIF);
      battery_voltage = ADC;
    }
    if (pwm_mirror && ch1_counts != 0 && ch2_counts != 0) {
      OCR0A = ch1_counts;
      OCR0B = ch2_counts;
    }
  }
}

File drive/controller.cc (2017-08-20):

#include <math.h>
#include <stdint.h>
#include <stdio.h>
#include <iostream>

#include "drive/controller.h"
#include "drive/imgproc.h"

using Eigen::Matrix2f;
using Eigen::Matrix3f;
using Eigen::Matrix4f;
using Eigen::MatrixXf;
using Eigen::Vector2f;
using Eigen::Vector3f;
using Eigen::VectorXf;

static const float MAX_THROTTLE = 0.8;
static const float SPEED_LIMIT = 5.0;

static const float ACCEL_LIMIT = 4.0;  // maximum dv/dt (m/s^2)
static const float BRAKE_LIMIT = -100.0;  // minimum dv/dt
static const float TRACTION_LIMIT = 4.0;  // maximum v*w product (m/s^2)
static const float kpy = 1.0;
static const float kvy = 2.0;

static const float LANE_OFFSET = 0.0;
static const float LANEOFFSET_PER_K = 0.0;
// this is actually used in model.py, not here
static const float METERS_PER_ENCODER_TICK = M_PI * 0.101 / 20;


DriveController::DriveController() {
  ResetState();
}

void DriveController::ResetState() {
  ekf.Reset();
  firstframe_ = true;
}

static inline float clip(float x, float min, float max) {
  if (x < min) return min;
  if (x > max) return max;
  return x;
}

void DriveController::UpdateCamera(const uint8_t *yuv) {
  Vector3f B;
  Matrix4f Rk = Matrix4f::Zero();
  float yc;

  if (!TophatFilter(yuv, &B, &yc, &Rk)) {
    return;
  }

  // ok, we've obtained our linear fit B and our measurement covariance Rk
  // now do the sensor fusion step

  float a = B[0], b = B[1], c = B[2];
  ekf.UpdateCenterline(a, b, c, yc, Rk);
}

void DriveController::UpdateState(const uint8_t *yuv, size_t yuvlen,
      float throttle_in, float steering_in,
      const Vector3f &accel, const Vector3f &gyro,
      uint8_t servo_pos, const uint16_t *wheel_encoders, float dt) {
  Eigen::VectorXf &x_ = ekf.GetState();
  if (isinf(x_[0]) || isnan(x_[0])) {
    fprintf(stderr, "WARNING: kalman filter diverged to inf/NaN! resetting!\n");
    ResetState();
    // exit(1);
    return;
  }

  if (firstframe_) {
    memcpy(last_encoders_, wheel_encoders, 4*sizeof(uint16_t));
    firstframe_ = false;
  }

  ekf.Predict(dt, throttle_in, steering_in);
  std::cout << "x after predict " << x_.transpose() << std::endl;

#if 1
  if (yuvlen == 640*480 + 320*240*2) {
    UpdateCamera(yuv);
    std::cout << "x after camera " << x_.transpose() << std::endl;
  } else {
    fprintf(stderr, "DriveController::UpdateState: invalid yuvlen %ld\n",
        yuvlen);
  }
#endif

  ekf.UpdateIMU(gyro[2]);
  std::cout << "x after IMU (" << gyro[2] << ")" << x_.transpose() << std::endl;

  // hack: force psi_e forward-facing
  if (x_[3] > M_PI/2) {
    x_[3] -= M_PI;
  } else if (x_[3] < -M_PI/2) {
    x_[3] += M_PI;
  }

  // read / update servo & encoders
  // use the average of the two rear encoders as we're most interested in the
  // motor speed
  // but we could use all four to get turning radius, etc.
  // since the encoders are just 16-bit counters which wrap frequently, we only
  // track the difference in counts between updates.
  printf("encoders were: %05d %05d %05d %05d\n"
         "      are now: %05d %05d %05d %05d\n",
      last_encoders_[0], last_encoders_[1], last_encoders_[2], last_encoders_[3],
      wheel_encoders[0], wheel_encoders[1], wheel_encoders[2], wheel_encoders[3]);

  // average ds among wheel encoders which are actually moving
  float ds = 0, nds = 0;
  for (int i = 2; i < 4; i++) {  // only use rear encoders
    if (wheel_encoders[i] != last_encoders_[i]) {
      ds += (uint16_t) (wheel_encoders[i] - last_encoders_[i]);
      nds += 1;
    }
  }
  memcpy(last_encoders_, wheel_encoders, 4*sizeof(uint16_t));
  // and do an EKF update if the wheels are moving.
  if (nds > 0) {
    ekf.UpdateEncoders(ds/(nds * dt), servo_pos);
    std::cout << "x after encoders (" << ds/dt << ") " << x_.transpose() << std::endl;
  } else {
    ekf.UpdateEncoders(0, servo_pos);
    std::cout << "x after encoders (" << ds/dt << ") " << x_.transpose() << std::endl;
  }

  std::cout << "P " << ekf.GetCovariance().diagonal().transpose() << std::endl;
}

static float MotorControl(float accel,
    float k1, float k2, float k3, float k4,
    float v) {
  float a_thresh = -k3 * v - k4;
  // voltage (1 or 0)
  float V = accel > a_thresh ? 1 : 0;
  // duty cycle
  float DC = clip(
      (accel + k3*v + k4) / (V*k1 - k2*v),
      0, 1);
  return V == 1 ? DC : -DC;
}

bool DriveController::GetControl(float *throttle_out, float *steering_out,
    float dt) {
  const Eigen::VectorXf &x_ = ekf.GetState();
  float v = x_[0];
  float delta = x_[1];
  float y_e = x_[2];
  float psi_e = x_[3];
  float kappa = x_[4];
  float ml_1 = x_[5];
  float ml_2 = x_[6];
  float ml_3 = x_[7];
  float ml_4 = x_[8];
  float srv_a = x_[9];
  float srv_b = x_[10];
  float srv_r = x_[11];

  float k1 = exp(ml_1), k2 = exp(ml_2), k3 = exp(ml_3), k4 = exp(ml_4);

  float vmax = fmin(SPEED_LIMIT, (k1 - k4)/(k2 + k3));

  // TODO: race line following w/ particle filter localization
  float lane_offset = clip(LANE_OFFSET + kappa * LANEOFFSET_PER_K, -1.0, 1.0);
  float psi_offset = 0;

  float cpsi = cos(psi_e - psi_offset),
        spsi = sin(psi_e - psi_offset);
  float dx = cpsi / (1.0 - kappa*y_e);

  // Alain Micaelli, Claude Samson. Trajectory tracking for unicycle-type and
  // two-steering-wheels mobile robots. [Research Report] RR-2097, INRIA. 1993.
  // <inria-00074575>

  // it's a little backwards though because our steering is reversed w.r.t. curvature
  float k_target = dx * (-(y_e - lane_offset) * dx * kpy*cpsi - spsi*(-kappa*spsi - kvy*cpsi) + kappa);

  *steering_out = clip((k_target - srv_b) / srv_a, -1, 1);
  if (*steering_out == -1 || *steering_out == 1) {
    // steering is clamped, so we may need to further limit speed
    float w_target = v * k_target;
    float k_limit = srv_a * (*steering_out) + srv_b;
    vmax = fmin(vmax, w_target / k_limit);
  }

  float v_target = fmin(vmax, sqrtf(TRACTION_LIMIT / fabs(k_target)));
  float a_target = clip(v_target - v, BRAKE_LIMIT, ACCEL_LIMIT) / dt;
  if (a_target > 0) {  // accelerate more gently than braking
    a_target /= 4;
  }
  *throttle_out = clip(
       MotorControl(a_target, k1, k2, k3, k4, v),
       -1, MAX_THROTTLE);

  printf("steer_target %f delta %f v_target %f v %f a_target %f lateral_a %f/%f v %f y %f psi %f\n",
      k_target, delta, v_target, v, a_target, v*v*delta, TRACTION_LIMIT, v, y_e, psi_e);

  printf("  throttle %f steer %f\n", *throttle_out, *steering_out);
  return true;
}

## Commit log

2013-12-04 Blinking LED on outboard atmega328p. woo.
2013-12-04 SPI hello world woo
2013-12-05 read 16-bit 20MHz timer via SPI
2013-12-06 Read 2-channel PWM input, make it available on SPI
    I can't believe I got this to work with such small jitter. It bounces
    around by about 10-15 counts but is usually pretty dead-on. I might do
    a histogram and add an input filter.
    Something is a little funky electrically: it only works if pullups are
    enabled, which leads me to believe either the radio is open collector or
    its output impedance is pretty high. Nevertheless, with my 10k/10k
    resistor divider, it works. I need a scope to see what's actually going
    on, but I don't think I can possibly be exceeding 3.3V on the input
    pins at least.
    [main.c]
2013-12-07 PWM output; mirroring input pulse duration
    but it's pretty ugly; only ~6 bits of precision. Which is probably
    plenty for the application, actually.
2013-12-09 8-bit pwm capture queue via SPI
    uses only 8-bit TMR0 for capture as that's also what's used for
    generation. can probably optimize some more now.
2013-12-09 don't blink the LED so fast.
2013-12-12 Fixed bad checksum read errors from GPS.
    Turns out the serial port had friggin' XON/XOFF flow control, so a 0x11
    appearing in binary data would be silently dropped! ARGH!
    Also, when first enabling the UART transmitter on the RPi, it glitches a
    start bit, so if you immediately start sending you get a framing error
    (thanks, logic analyzer! I never would have noticed otherwise...).
    Added a 1ms delay and a spurious \r\n\r\n.
2013-12-26 battery sense wire
    this seems a bit too noisy right now; not sure what the deal is
2014-03-09 Adding i2c IMU code
2014-03-09 gyro + compass working
2014-03-10 accelerometer reading + notes
2014-03-16 make i2c-imu a library
2014-03-30 adjustments to IMU bandwidth/samplerates
2014-03-30 imu: output pretty printing, sync to system clock @ 50Hz
2014-03-31 imu: better poll timing
2014-04-14 adding EAGLE schematic + pcb
    [untitled.brd, untitled.sch]
2014-04-14 Better PCB annotations, moved stuff and re-routed
    [untitled.brd]
2014-04-14 critical PCB connector fixes
    - flipped RPi connector around to correct orientation
    - flipped SiRF GPS connector around
    - added two more resistors to radio input, so there's a resistor
    divider instead of relying on overload protection
    - powered LCD backlight LED by 5v instead of 3.3v, resistor can adjust
    brightness
    [untitled.brd, untitled.sch]
2014-04-30 Some AVR changes to accomodate new circuit board
2014-04-30 LCD/SPI refactoring & cleanup
    (N.B. I broke it with this commit, need to debug)
    [lcd.cc]
2014-04-30 fix lcd init bugs, add more interesting test
    [lcd.cc]
2014-04-30 LCD: add text drawing, fix contrast
    [lcd.cc]
2014-04-30 avr: brown-out detect + watchdog
    [main.c]
2014-05-02 Add battery voltage measurement
2014-05-04 add imu + input logger
    (need to add gps support to the logger also)
    also swapped steering/throttle; i must have had it backwards before
    [log.cc, radio.cc]
2014-05-04 ADXL345: fix wrong rate code
    was actually sampling at 25Hz, not 50Hz. Doh!
    [imu.cc]
2014-08-23 raise magnetometer sample rate, fix radio input glitch
    [imu.cc, radio.cc]
2014-09-07 switch to my fork of userland until merge
2014-09-07 Stripped extra junk out of cam code
    also added a dumb script to show I420 YUV frames captured by the camera
2014-09-07 Cpplint style cleanup
    run with: cpplint.py --filter=-legal *.cc *.h */*.cc */*.h
2014-09-08 Don't use gcc extensions for initializing camera structures
2014-09-10 camera/vis: support stdin/stdout streaming
2014-09-11 vis: 640x480 window, camera calibration experiment
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2014-09-27 camtest: specify fps on cmdline
    also played with buffering stuff but we still drop frames
2014-09-28 only update steering/throttle input state if valid
2014-09-28 fix startup servo glitch
    [main.c]
2014-09-28 new UI which captures camera, imu, gps, buttons
    the dithered display is buggy right now, need to fix (and gamma-correct)
    [imu.cc, imu_main.cc, log.cc]
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2014-10-14 better method, but man, my offsets are awful
    gotta move the sensor, i think
2014-10-14 trying to do tilt compensation, probably wrong
    [cal.cc, imu.cc]
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2014-10-16 kalman filter for bias estimation; still buggy
    [cal.cc]
2014-10-16 this kalman filter doesn't work at all
    there's a much simpler way to do this, coming next
    http://www.freescale.com/files/sensors/doc/app_note/AN4246.pdf
    [cal.cc]
2014-10-16 this least-squares solution works much better
    however, correlated inputs mess it up; maybe we can de-weight each
    sample based on informativeness (like, 1-dot product)
2014-10-16 weight calibration samples by cosine distance from previous
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2014-10-22 begin design of enclosure for all hardware
    just roughing out dimensions here relative to battery holder widget
    [platform.scad]
2014-10-22 roughing in an rpi
    [platform.scad]
2014-10-22 bosses with gussets
    [platform.scad]
2014-10-23 more accurate rpi
    [platform.scad, rpi.scad]
2014-10-23 better mounting thingies
    [platform.scad]
2014-10-23 manufacturability tweaks
    [platform.scad, rpi.scad]
2014-10-23 thinner walls, reinforcing ridges
    [platform.scad]
2014-10-30 feature point tracking across frames
    still pretty buggy, needs lots of tuning
    also i can draw lines now, yay
2014-10-30 fix drawline, print mph
    [platform.scad, rpi.scad]
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2015-10-17 more traxxas parts
    [platform.scad, traxxas.scad]
2015-10-17 added captive IMU mount
    [platform.scad, traxxas.scad]
2015-10-17 parametric camera holder thingy
    [platform.scad]
2015-10-17 several fixes after 1st print
    - lengthened entire part by 1mm
    - overbored all holes by .02" / 0.5mm to compensate for nozzle diameter
    / material infill
    - made bosses considerably thicker so they can be machined (maybe?)
    - moved camera mount into a separate part which mates with the existing
    screws
    - moved IMU mounting screw back a bit
    [platform.scad, traxxas.scad]
2015-10-17 Moved camera mount flush with front
    now it can be 3d printed without weird support issues
    [platform.scad]
2015-10-17 convert all to metric, clean up code and remove old junk
    [baseplate.scad, platform.scad, traxxas.scad]
2015-10-17 update baseplate
    [baseplate.scad]
2015-12-19 forgot to add fasteners.scad
    [fasteners.scad]
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2016-01-08 redoing raspberry pi + battery + camera mounts
    [v2.scad]
2017-01-21 added plate between servomount and rpi box
    [baseplate.scad, v2.scad]
2017-02-20 a bunch of work in progress
    switching from janky usb-serial microcontroller to PCA9685 servo
    control, bluetooth controller input instead of PWM sampling
    switching to MPU9250 instead of three-device frankenstein
    also discovered some bad math but not the correct math
    [imu_log.cc, log.cc, mpu9150.cc]
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2017-04-01 various experiments which seem to help
    nearly able to localize with a particle filter, I think...
2017-05-11 add camera holder .scad
    [camholder.scad]
2017-05-11 make the camera holder taller
    can't 3d print anything bigger than this
    [camholder.scad]
2017-05-14 neat PID controller. overshoots the turn, but simple.
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2017-05-14 disable mag cal for now; update filters and gyro range
2017-05-14 fix camera callback crash on exit
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2017-05-14 an EKF that actually works!!!!!!
    it's able to determine the car's velocity and the track curvature
    through the interplay of control inputs, gyro reading, and linear
    regression of the detected yellow center markers.
2017-05-14 ported EKF to C++/Eigen
    TODO: PID drive code
2017-05-14 FINALLY, a dialed-in PD controller.
    On the full size track I can reduce P a bit and raise the traction
    limit (in the driveway I get lost and crash).
    [controller.cc, drive.cc]
2017-05-14 another error in the control law, this one minor
    sin^2 psi times curvature was negative, but that's a pretty small
    correction (usually).
    [controller.cc]
2017-05-17 this thing *FLIES* now with ESC out of traing mode
    had to reduce the throttle limit until it learns about braking and
    lateral dynamics...
2017-05-21 made a new circuit board tray thing
    [baseplate.scad, camholder.scad, rpi.scad]
2017-06-02 remove dead UI code
    "drive" replaces this functionality now
    [imu.cc]
2017-06-15 racing line optimizer
    saved out a racing line relative to centerline markings; combined with
    particle filter localization, should be able to drive along racing line
    and beat the course in ~9 seconds
2017-06-16 updated simulator + driver code
    - loads properly (meter-) scaled track
    - PD steering as before but drives on precomputed racing line
    - rethought throttle control; velocity based on curvature, braking
    based on curvature lookahead
2017-06-16 assorted updates
    [baseplate.scad, camholder.scad]
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2017-07-09 refinements to camera holders
    plus a new one for the arducam form factor.
    [camholder-arducam.scad]
2017-07-09 adjust lens hole center
    [camholder.scad]
2017-07-16 fix all kinds of bugs
    [controller.cc, drive.cc]
2017-07-16 teensy lib fixes
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2017-08-10 holy stupid bugs batman!
    this thing finally runs correctly!!!!!!!!1
    [controller.cc, drive.cc]
2017-08-11 oops, bug in motor control math
    [controller.cc]
2017-08-12 fix bug w/ motor control, average all moving encoders
    (and don't apply wheel encoder update at all if none are moving)
    [controller.cc]
2017-08-12 smooth as butter now. awesome.
    still might need some process noise tuning, still need to figure out
    what's wrong with the IMU updates, it still might get lost if it
    completely loses the line...
    but this is pretty badass now.
    [controller.cc]
2017-08-14 code used during the 2017-08-12 event
    the floor was super slippery, so i had to turn the top speed and
    transverse / lateral accelerations way down :(
    soon we'll learn how to drift.
    [controller.cc]
2017-08-17 back on track with fixed EKF model
    [controller.cc, drive.cc]
2017-08-17 more bugs! more tuning!
    there's something wrong with motor control; that's what i need to fix
    next. it's overshooting turns, and i have to raise P and D to keep it
    tight but it oscillates too much now.
    [controller.cc]
2017-08-19 brake more aggressively; esp. when steering is maxed out
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2017-08-20 updated teensy code & 3d models
    [baseplate.scad]
2020-02-15 ubx navmsg updates
    for some reason i also clang-formatted the IMU code

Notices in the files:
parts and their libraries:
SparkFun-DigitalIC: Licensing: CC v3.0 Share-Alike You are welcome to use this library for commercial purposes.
